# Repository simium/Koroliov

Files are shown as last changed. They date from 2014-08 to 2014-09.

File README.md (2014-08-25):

Koroliov
========

Flight hardware and software for the Koroliov SSDV project.

Modules used in this version:
* Arduino Micro: http://arduino.cc/en/Main/arduinoBoardMicro
* Radiometrix NTX2: http://www.radiometrix.com/content/ntx2
* TTL Serial JPEG Camera: https://www.adafruit.com/product/397
* Altitude/Pressure/Temperature sensor - MPL3115A2: https://www.sparkfun.com/products/11084
* MicroSD card breakout: https://www.adafruit.com/products/254

Future modules that could be added:
* Radiometrix NTX2B: http://www.radiometrix.com/content/ntx2b
* Adafruit's Ultimate GPS: https://www.adafruit.com/products/746

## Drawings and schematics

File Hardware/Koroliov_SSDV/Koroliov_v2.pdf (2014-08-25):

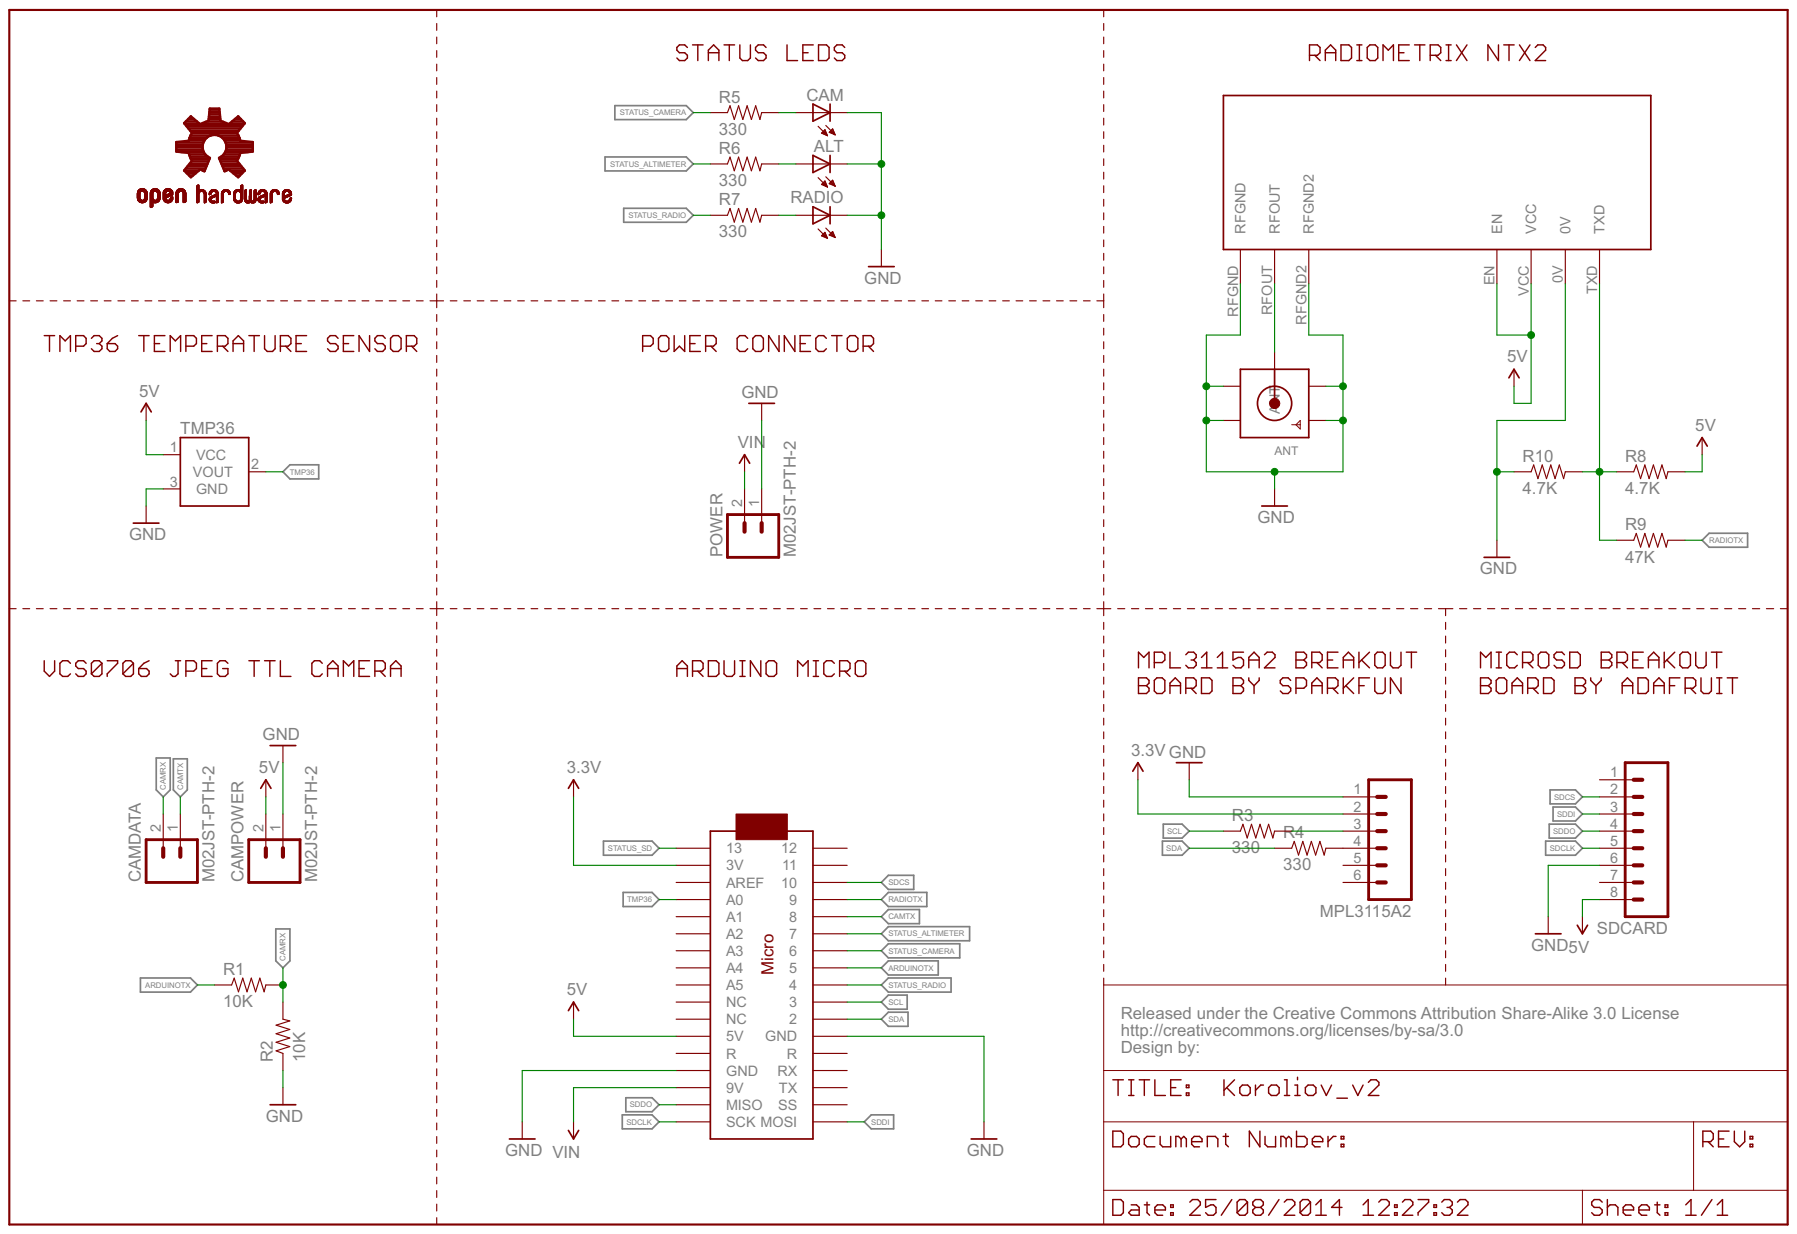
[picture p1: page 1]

Released under the Creative Commons Attribution Share-Alike 3.0 License
http://creativecommons.org/licenses/by-sa/3.0
Design by:

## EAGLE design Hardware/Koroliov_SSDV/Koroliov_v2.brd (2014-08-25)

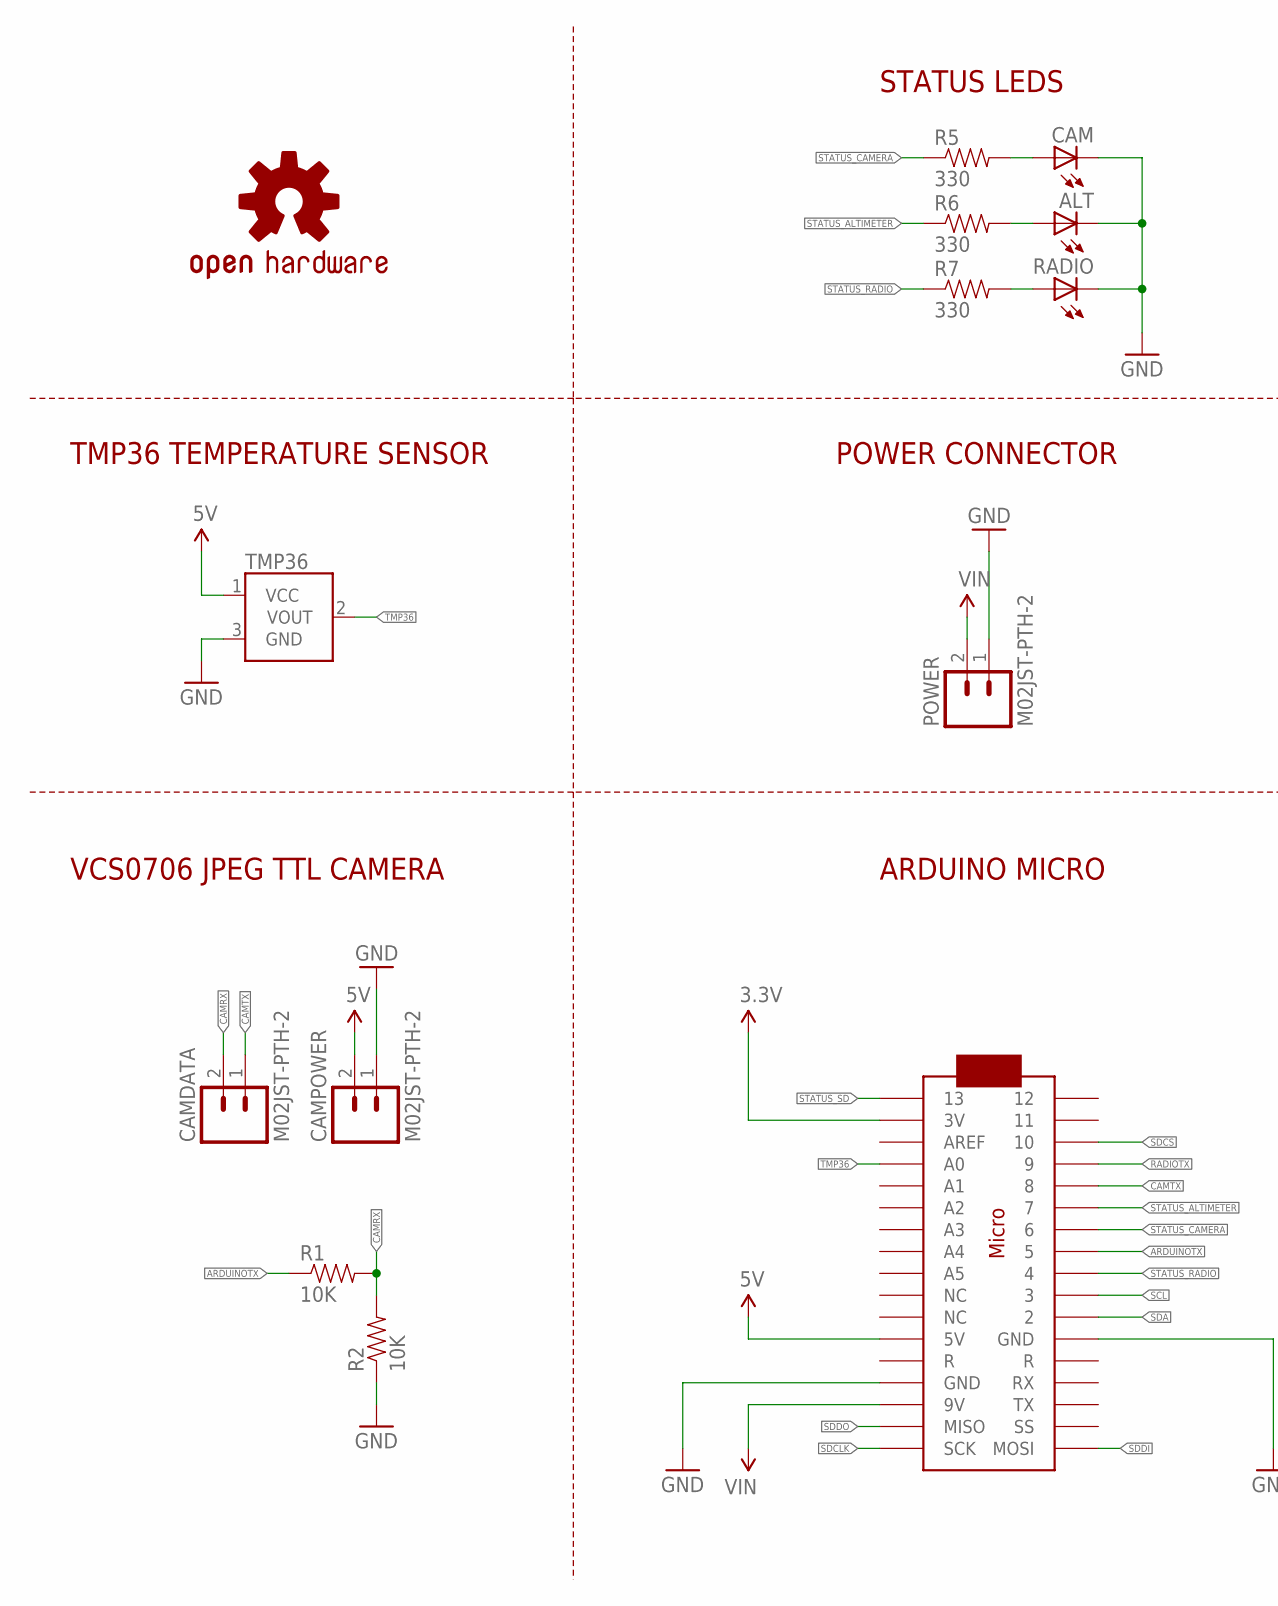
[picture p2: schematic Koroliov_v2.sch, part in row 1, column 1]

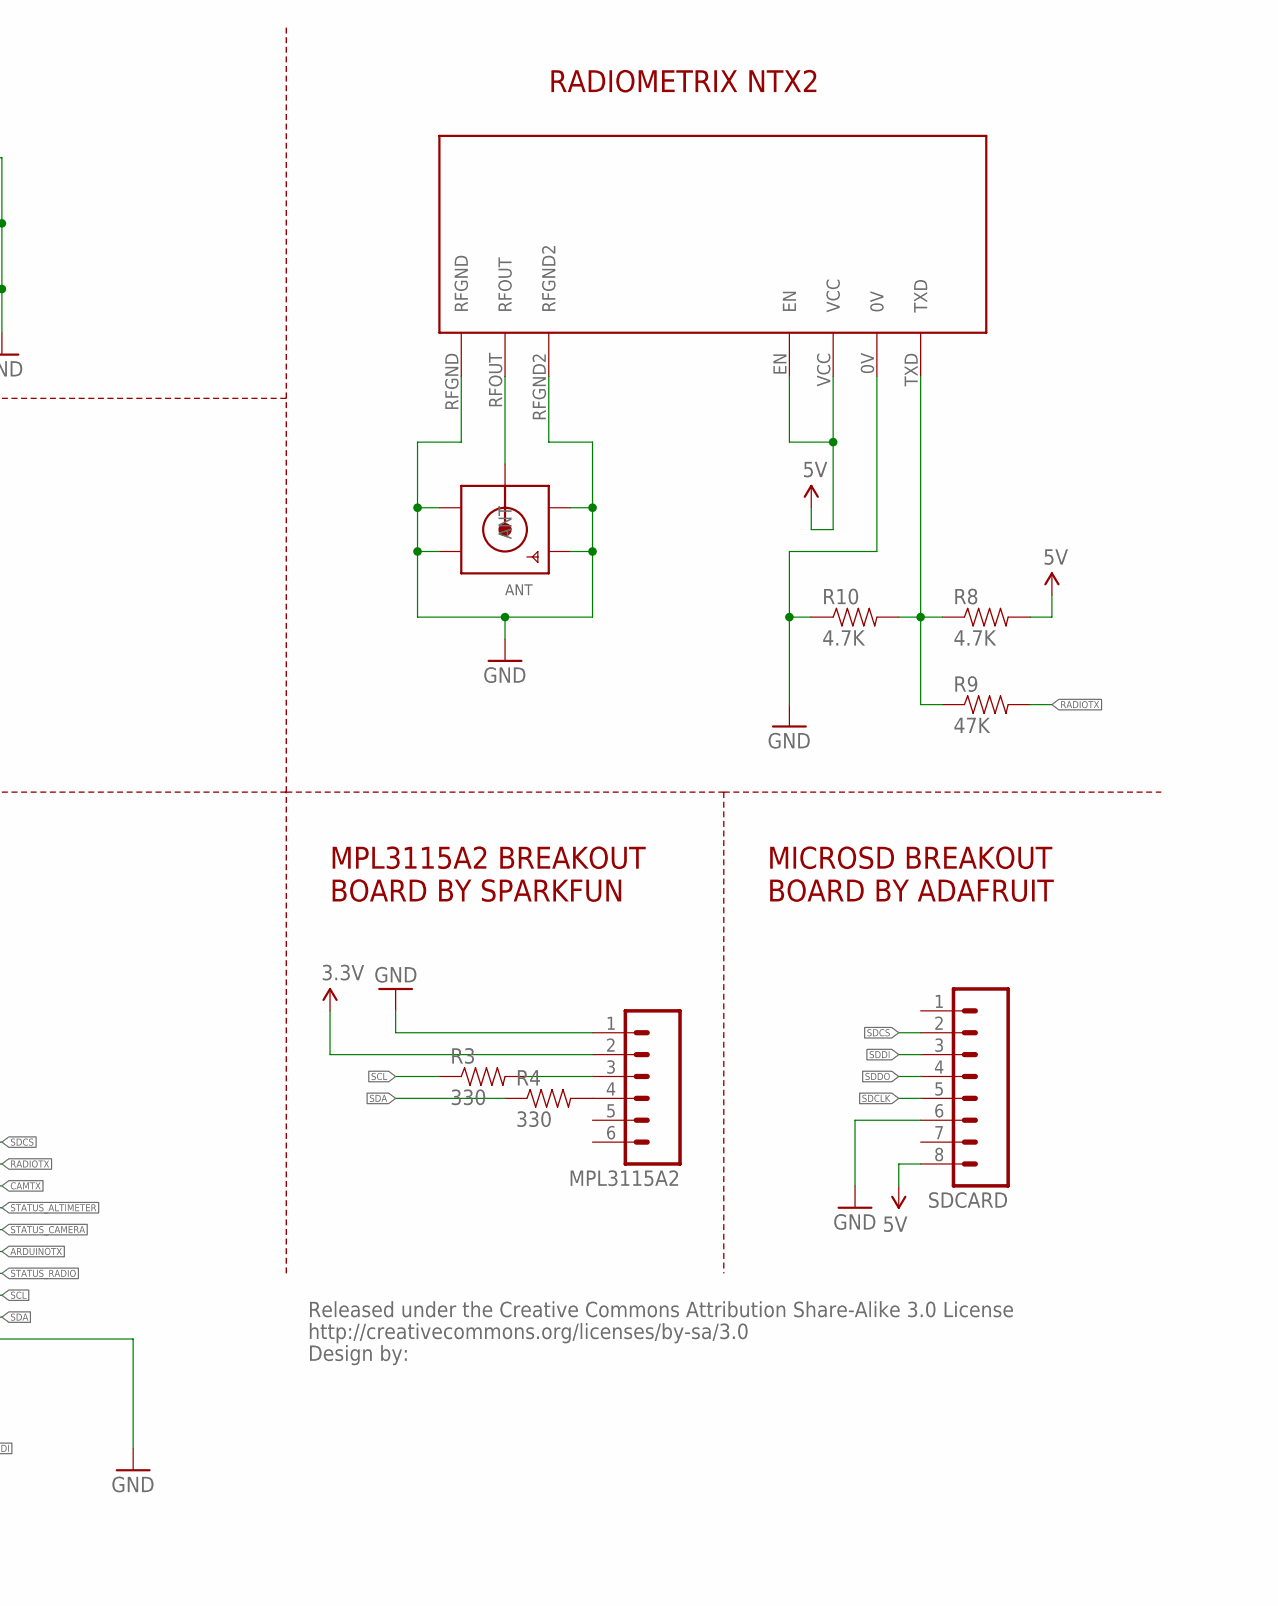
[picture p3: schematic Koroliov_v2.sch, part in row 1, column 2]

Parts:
ALT: LED1206; LED-1206
ANT: SMACONNECTOR_EDGE; SMA_EDGELAUNCH
ARDUINOMICRO: ARDUINOMICRO
CAM: LED1206; LED-1206
CAMDATA: M02JST-PTH-2; JST-2-PTH
CAMPOWER: M02JST-PTH-2; JST-2-PTH
CC_TEXT1: CREATIVE_COMMONS
LOGO1: OSHW-LOGOL; OSHW-LOGO-L
MPL3115A2: M06SIP; 1X06
NTX2: NTX2
POWER: M02JST-PTH-2; JST-2-PTH
R1, R2: 10K; 1206
R3, R4, R5, R6, R7: 330; 1206
R8, R10: 4.7K; 1206
R9: 47K; 1206
RADIO: LED1206; LED-1206
SDCARD: M081X08; 1X08
TMP36: TMP36GT9; TO-92

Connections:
3.3V: ARDUINOMICRO.P$33 (3V), MPL3115A2.2
5V: ARDUINOMICRO.P$23 (5V), CAMPOWER.2, NTX2.EN, NTX2.VCC, R8.2, SDCARD.8, TMP36.1 (VCC)
ARDUINOTX: ARDUINOMICRO.P$8 (5), R1.1
CAMRX: CAMDATA.2, R1.2, R2.2
CAMTX: ARDUINOMICRO.P$5 (8), CAMDATA.1
GND: ALT.C, ANT.GND@1 (GND4), ANT.GND@2 (GND3), ANT.GND@3 (GND2), ANT.GND@4 (GND1), ARDUINOMICRO.P$12 (GND), ARDUINOMICRO.P$21 (GND), CAM.C, CAMPOWER.1, MPL3115A2.1, NTX2.0V, NTX2.RFGND, NTX2.RFGND2, POWER.1, R2.1, R10.1, RADIO.C, SDCARD.6, TMP36.3 (GND)
unnamed: ANT.P (ANT), NTX2.RFOUT
unnamed: CAM.A, R5.2
unnamed: ALT.A, R6.2
unnamed: MPL3115A2.3, R3.2
unnamed: MPL3115A2.4, R4.2
unnamed: R7.2, RADIO.A
unnamed: NTX2.TXD, R8.1, R9.1, R10.2
RADIOTX: ARDUINOMICRO.P$4 (9), R9.2
SCL: ARDUINOMICRO.P$10 (3), R3.1
SDA: ARDUINOMICRO.P$11 (2), R4.1
SDCLK: ARDUINOMICRO.P$18 (SCK), SDCARD.5
SDCS: ARDUINOMICRO.P$3 (10), SDCARD.2
SDDI: ARDUINOMICRO.P$17 (MOSI), SDCARD.3
SDDO: ARDUINOMICRO.P$19 (MISO), SDCARD.4
STATUS_ALTIMETER: ARDUINOMICRO.P$6 (7), R6.1
STATUS_CAMERA: ARDUINOMICRO.P$7 (6), R5.1
STATUS_RADIO: ARDUINOMICRO.P$9 (4), R7.1
STATUS_SD: ARDUINOMICRO.P$34 (13)
TMP36: ARDUINOMICRO.P$31 (A0), TMP36.2 (VOUT)
VIN: ARDUINOMICRO.P$20 (9V), POWER.2

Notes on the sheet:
MPL3115A2 BREAKOUT BOARD BY SPARKFUN
MICROSD BREAKOUT BOARD BY ADAFRUIT
RADIOMETRIX NTX2
ARDUINO MICRO
STATUS LEDS
POWER CONNECTOR
TMP36 TEMPERATURE SENSOR
VCS0706 JPEG TTL CAMERA

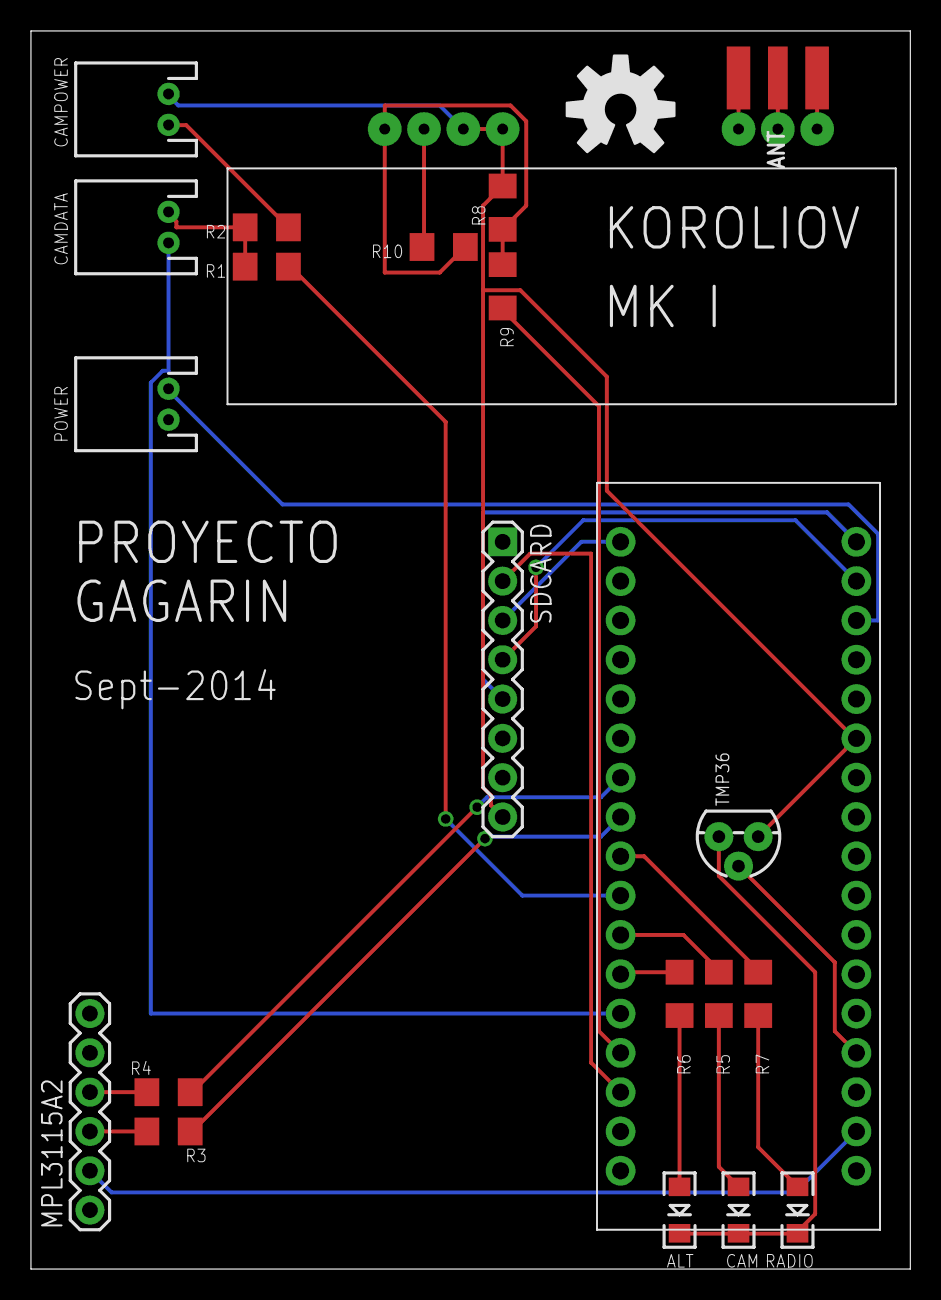
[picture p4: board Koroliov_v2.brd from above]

Board: 2 copper layers, 56.8 x 80.0 mm, 24 parts (0 on the bottom side), 25 nets.

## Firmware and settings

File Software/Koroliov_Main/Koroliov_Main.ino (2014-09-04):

/*

 RTTY code by Philip Heron <phil@sanslogic.co.uk> https://github.com/fsphil/
 Arduino project structure based on the CUBEX project by https://github.com/arkorobotics/
 
 Special thanks to http://ukhas.org.uk and the people in the IRC.
 
 GPS and Camera code by Adafruit.
 
 */

/* Includes */
#include <string.h>
#include<stdlib.h>
#include <util/crc16.h>
#include <Adafruit_VC0706.h>
#include <Adafruit_GPS.h>
#include <SoftwareSerial.h>
#include "ssdv.h"
#include "config.h"
#include "rtty.h"

#include <avr/wdt.h>

char datastring[80];
char temp_str[16+1];
char temp_str_aux[16+1];
char checksum_str[5+1];

int errorstatus=SSDV_ERROR;
unsigned char cameracode = 0x00;

SoftwareSerial camera_connection(CAM_RX_PIN, CAM_TX_PIN);
Adafruit_VC0706 cam = Adafruit_VC0706(&camera_connection);

Adafruit_GPS GPS(&Serial1);
HardwareSerial mySerial = Serial1;

_payload Koroliov;

static unsigned long previousTelemetrySeconds;
static unsigned long previousSSDVSeconds;

void setup() {
  pinMode(RADIO_TX_PIN,OUTPUT);
  pinMode(CUTDOWN_PIN, OUTPUT);

  setKoroliovPwmFrequency();
  analogReference(INTERNAL);

  /* Fix for CAM RX bug */
  pinMode(OLD_CAM_RX_PIN, INPUT);

  // Turn on the camera
  cam.begin();

  // Turn on the GPS
  GPS.begin(9600);
  GPS.sendCommand(PMTK_SET_NMEA_OUTPUT_ALLDATA);
  GPS.sendCommand(PMTK_SET_NMEA_UPDATE_1HZ);   // 1 Hz update rate

  Koroliov.descending = false;

  int i = 0;

  while (i<5) {
    if (update_payload_status(&Koroliov) != 0) {
      rtty_txtelemetry(&Koroliov);
      delay(1000);
      i++;
    }
  }

  wdt_enable(WDTO_8S);
}

void loop() {
  unsigned long currentSeconds = millis()/1000;

  if ((currentSeconds - previousTelemetrySeconds) >= TELEMETRY_INTERVAL) {
    previousTelemetrySeconds = millis()/1000;
    while(!update_payload_status(&Koroliov));
    rtty_txtelemetry(&Koroliov);
  }

  if ((currentSeconds - previousSSDVSeconds) >= SSDV_INTERVAL && (int)Koroliov.gps_altitude >= 500) {
    previousSSDVSeconds = millis()/1000;
    rtty_tximage();
  }

  /* Cutdown <- altitude >= 30000m and more than 7200 seconds passed since boot (almost 2 hours) */
  if ((int)Koroliov.gps_altitude >= 30000 && currentSeconds > 6000 && Koroliov.descending == false) {
    wdt_disable();
    digitalWrite(CUTDOWN_PIN, HIGH);
    delay(10*1000);
    digitalWrite(CUTDOWN_PIN, LOW);
    wdt_enable(WDTO_8S);

    Koroliov.descending = true;
  }

  wdt_reset();
}

int update_payload_status(struct _payload* payload) {
  int status = 0;

  char c = GPS.read();
  while (c!=0) {
    c = GPS.read();
  }

  if (GPS.newNMEAreceived()) {
    if (GPS.parse(GPS.lastNMEA())) {
      status = 1;

      payload->sentence_id++;
      payload->running_millis = millis();

      payload->gps_hour = GPS.hour;
      payload->gps_minute = GPS.minute;
      payload->gps_seconds = GPS.seconds;
      payload->gps_latitude = GPS.latitude;
      payload->gps_longitude = GPS.longitude;
      payload->gps_previous_altitude = payload->gps_altitude;
      payload->gps_altitude = GPS.altitude;

      /* TMP36 - Internal temperature */
      int temperatureReading = analogRead(TMP36_PIN);
      float voltage = temperatureReading * 2.56;
      voltage = voltage/1024.0;

      payload->internal_temperature = (voltage-0.5)*100;
    }
  }

  return status;
}

void rtty_txtelemetry(struct _payload* payload) {

  /* CALLSIGN */
  snprintf(datastring,80,"$$KRLV"); // Puts the text in the datastring

  /* Sentence ID */
  sprintf(temp_str, ",%lu", payload->running_millis/1000);
  strcat(datastring,temp_str);

  /* Time */
  sprintf(temp_str, ",%02d:%02d:%02d", payload->gps_hour, payload->gps_minute, payload->gps_seconds);
  strcat(datastring,temp_str);

  /* Latitude */
  dtostrf(payload->gps_latitude, 0, 6, temp_str_aux);
  sprintf(temp_str, ",%s", temp_str_aux);
  strcat(datastring,temp_str);

  /* Longitude */
  dtostrf(payload->gps_longitude, 0, 6, temp_str_aux);
  sprintf(temp_str, ",%s", temp_str_aux);
  strcat(datastring,temp_str);

  /* Altitude */
  dtostrf(payload->gps_altitude, 0, 1, temp_str_aux);
  sprintf(temp_str, ",%s", temp_str_aux);
  strcat(datastring,temp_str);

  /* Internal Temperature */
  dtostrf(payload->internal_temperature, 0, 2, temp_str_aux);
  sprintf(temp_str, ",%s", temp_str_aux);
  strcat(datastring,temp_str);

  /* CRC16 checksum */
  unsigned int CHECKSUM = gps_CRC16_checksum(datastring); // Calculates the checksum for this datastring
  sprintf(checksum_str, "*%04X\n\0", CHECKSUM);
  strcat(datastring,checksum_str);

  rtx_string (datastring);
}

void rtty_tximage(void)
{
  static char setup = 0;
  static uint8_t img_id = 0;
  static ssdv_t ssdv;
  static uint8_t pkt[SSDV_PKT_SIZE];
  static uint8_t img[32];
  int r;

  static uint8_t imgsize; 
  static uint16_t jpglen;

  if(!setup)
  {
    setup = -1;

    wdt_reset();

    cam.reset();
    cam.setImageSize(VC0706_320x240);
    cam.setCompression(255);

    imgsize = cam.getImageSize();

    if (cam.takePicture()) {
      jpglen = cam.frameLength();
    }
    else {
      jpglen = 0;
    }

    ssdv_enc_init(&ssdv, RTTY_CALLSIGN, img_id++);
    ssdv_enc_set_buffer(&ssdv, pkt);                  
  }

  while((r = ssdv_enc_get_packet(&ssdv)) == SSDV_FEED_ME)
  {
    uint8_t *buffer; 
    uint8_t bytesToRead = min(32, jpglen); // change 32 to 64 for a speedup but may not work with all setups!
    buffer = cam.readPicture(bytesToRead);

    ssdv_enc_feed(&ssdv, buffer, bytesToRead);
    jpglen -= bytesToRead;

    wdt_reset();
  }

  if(r != SSDV_OK || !(jpglen > 0))
  {
    setup = 0;
    cam.resumeVideo();
  }

  cameracode = r;

  // Got the packet! Transmit it //
  rtx_data(pkt, SSDV_PKT_SIZE);
}

uint16_t gps_CRC16_checksum (char *string) {
  size_t i;
  uint16_t crc;
  uint8_t c;

  crc = 0xFFFF;

  // Calculate checksum ignoring the first two $s
  for (i = 2; i < strlen(string); i++)
  {
    c = string[i];
    crc = _crc_xmodem_update (crc, c);
  }

  return crc;
}

void setKoroliovPwmFrequency() {
  /* Radio pin is always 9 in Koroliov board */
  TCCR1B = TCCR1B & 0b11111000 | 0x01;
}

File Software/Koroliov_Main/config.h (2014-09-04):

#ifndef __CONFIG_H__
#define __CONFIG_H__

#include <stdint.h>
#include <Arduino.h>

#define RTTY_CALLSIGN "KRLV"

/* CONFIGURABLE BITS */
#define ASCII 8          // ASCII 7 or 8
#define STOPBITS 2       // Either 1 or 2
#define TXDELAY 0        // Delay between sentence TX's
#define RTTY_BAUD 300     // Baud rate for use with RFM22B Max = 600

#define TX_DELAY      300   // default was 300

#define RADIO_FREQUENCY      (434650000UL)

/* Useful Constants */
#define SECS_PER_MIN  (60UL)
#define SECS_PER_HOUR (3600UL)
#define SECS_PER_DAY  (SECS_PER_HOUR * 24L)
#define TELEMETRY_INTERVAL (30)
#define SSDV_INTERVAL      (1)

/* Useful Macros for getting elapsed time */
#define numberOfSeconds(_time_) (_time_ % SECS_PER_MIN)  
#define numberOfMinutes(_time_) ((_time_ / SECS_PER_MIN) % SECS_PER_MIN) 
#define numberOfHours(_time_) (( _time_% SECS_PER_DAY) / SECS_PER_HOUR)
#define elapsedDays(_time_) ( _time_ / SECS_PER_DAY)  

/* Digital pins */
#define OLD_CAM_RX_PIN         (4)
#define CAM_RX_PIN         (8)
#define CAM_TX_PIN         (5)
#define RADIO_TX_PIN         (9)
#define CUTDOWN_PIN         (13)
//#define STATUS_RADIO_LED     (8)
//#define STATUS_ALTIMETER_LED (7)
//#define STATUS_CAMERA_LED    (6)
//#define CAM_RX_PIN           (5)
//#define CAM_TX_PIN           (4)
//#define I2C_SCL_PIN          (3)
//#define I2C_SDA_PIN          (2)

/* Analog pins */
#define TMP36_PIN            (A0)

#define IMAGE_SIZE_LARGE     (3)
#define IMAGE_SIZE_MEDIUM    (2)
#define IMAGE_SIZE_SMALL     (1)

struct _payload {
  uint8_t sentence_id;
  unsigned long running_millis;
  uint8_t   gps_hour;
  uint8_t   gps_minute;
  uint8_t   gps_seconds;
  uint16_t  gps_milliseconds;
  uint8_t   gps_year;
  uint8_t   gps_month;
  uint8_t   gps_day;
  float gps_latitude;
  float gps_longitude;
  float gps_altitude;
  float gps_previous_altitude;
  float gps_geoidheight;
  float internal_temperature;
  boolean descending;
};

#endif

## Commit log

2014-07-29 First commit of the hardware
    This is the board currently sent to fabrication.
    [Koroliov_v2.brd, Koroliov_v2.sch]
2014-08-25 Fixes after first fabrication
    Arduino Micro was not fully compatible with previous layout for the
    camera and the SD card. Antenna SMA connector has been moved to edge for
    better connection with antenna cable.
    [Koroliov_v2.brd, Koroliov_v2.sch]
2014-08-29 RTTY and SSDV finally at 300 bps
    Works flawlessly. Current code keeps the camera sending images for 4
    hours with only 6 AA batteries, thinking how to optimize radio use.
2014-09-04 RTTY, SSDV and GPS at 300 baud
    I2C device removed, added GPS. Everything is being fine tuned.

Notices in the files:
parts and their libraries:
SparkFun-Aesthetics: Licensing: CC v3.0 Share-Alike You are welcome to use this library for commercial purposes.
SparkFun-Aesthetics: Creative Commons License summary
